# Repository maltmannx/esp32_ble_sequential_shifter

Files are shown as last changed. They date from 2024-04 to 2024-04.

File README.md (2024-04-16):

# DIY Sequential Shifter ESP32 BLE ver.
## *This project is still in progress and will subject to change.*
**This project was beased on** https://www.thingiverse.com/thing:4557771  
I simplify the code and manage to make it possible running on a Espressif ESP32 dev kit(no USBHID support) with BLE. 
## Dependency and Library
https://github.com/lemmingDev/ESP32-BLE-Gamepad  
This library turns ESP32 a BLE gamepad that fits multiple scenarios.
## Functions
The original code will turn ESP32 a bluetooth gamepad. When device paired, the board listens to 2 pins input (D25 and D34) as shifting up and down. The on-board led blink twice for shifting up, and once for down. When long-pressing the button (default 800ms), 2 extra physical buttons will be triggered. You can modify the io ports and functions to your like.

## Usage
+ Git clone or download the zip file and decompress.
+ Install VS Code and PlatformIO extension.
+ Select and download the right board driver (ESP32 Dev Kit).
+ Modify sequential_shifter.cpp that fits your perfers.
+ Connect the board and choose the right com port.
+ Build and upload the ROM (hold boot button).
+ Test functions and assembling.
+ Bind keys in game.

## Components needed (Chinese ver.)
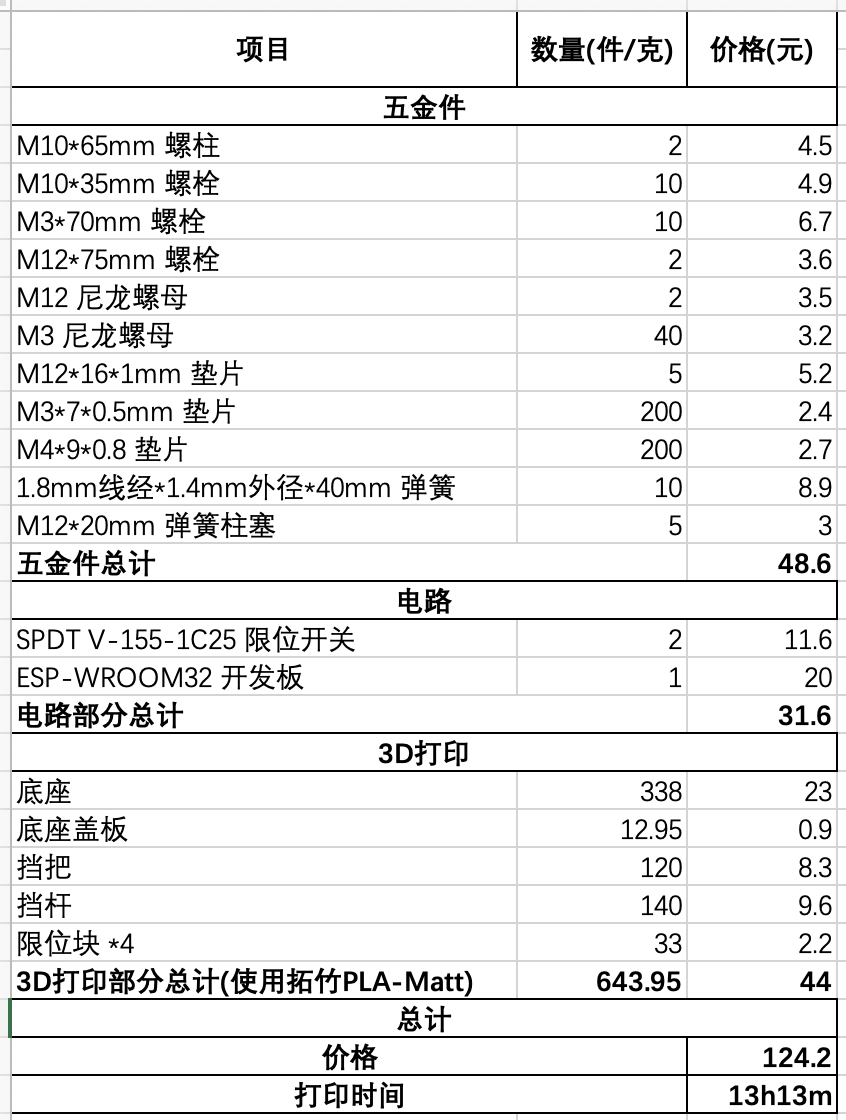
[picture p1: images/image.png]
components table

Sheets are attached above.

## About 3D printing parts
I slightly adjust the printing parameters. They're about 20% heavier but more stong and reliable. If you hava a BambuLab printer, you can simply import the .3mf file and start printing with PLA-Matt. For any non-bambulab devices, here are the per-component settings:
+ MainBody: 4 walls, 50% adaptive cubic infill with support
+ ShifterShaft: 4 walls, 50% adaptive cubic infill with support
+ Knob: 4 walls, 100% infill
+ Spacer, and bottom cover: 3 walls, 100% infill

**Total filaments used: 650.65g**  
**Total Printing time: 13h13m**

## Acknowledgements
 Introducing my friend and personal sim-racing coach @SanchezYao. I will never made it without his support.  
 Special thanks to [BambuLab](https://bambulab.com/en) for a new P1SC printer and filaments. Their products are one of the most reliable devices you can find in current days.

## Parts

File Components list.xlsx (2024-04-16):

项目 | 数量(件/克) | 价格(元)
五金件
M10*65mm 螺柱 | 2 | 4.5
M10*35mm 螺栓 | 10 | 4.9
M3*70mm 螺栓 | 10 | 6.7
M12*75mm 螺栓 | 2 | 3.6
M12 尼龙螺母 | 2 | 3.5
M3 尼龙螺母 | 40 | 3.2
M12*16*1mm 垫片 | 5 | 5.2
M3*7*0.5mm 垫片 | 200 | 2.4
M4*9*0.8 垫片 | 200 | 2.7
1.8mm线经*1.4mm外径*40mm 弹簧 | 10 | 8.9
M12*20mm 弹簧柱塞 | 5 | 3
五金件总计 |  | 48.6
电路
SPDT V-155-1C25 限位开关 | 2 | 11.6
ESP-WROOM32 开发板 | 1 | 20
电路部分总计 |  | 31.6
3D打印
底座 | 338 | 23
底座盖板 | 12.95 | 0.9
挡把 | 120 | 8.3
挡杆 | 140 | 9.6
限位块 *4 | 33 | 2.2
3D打印部分总计(使用拓竹PLA-Matt) | 643.95 | 44
总计
价格 |  | 124.2
打印时间 |  | 13h13m

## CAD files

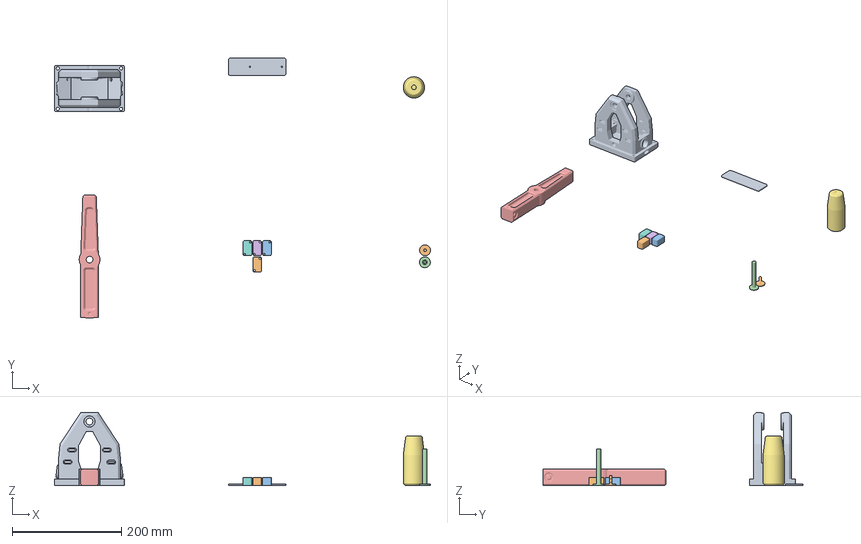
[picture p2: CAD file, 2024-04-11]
shifter.3mf
688.5 x 475.5 x 133.7 mm
MainBody.stl
PivotCap.stl
SwitchSpacer.stl x 4
PivotPin.stl
ShifterShaft.stl
Knob.stl
BottomCover.stl

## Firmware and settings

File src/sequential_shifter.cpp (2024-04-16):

#include <Arduino.h>
#include <BleGamepad.h> // https://github.com/lemmingDev/ESP32-BLE-Gamepad

#define BUTTONPIN1 5
#define BUTTONPIN2 21
// Pin button is attached to

#define LONGPRESS 500
// any pressing longer than 500ms will be triggered as long press

#define LED 2
// on-board LED(optional)

// add on-press buttons here
int button[] = {BUTTON_1, BUTTON_2};
// add on-longpress buttons here
int longPressButton[] = {BUTTON_3, BUTTON_4};

// bluetooth ssid can be modified, defalut:
// BleGamepad(std::string deviceName = "ESP32 BLE Gamepad", std::string deviceManufacturer = "Espressif", uint8_t batteryLevel = 100);
BleGamepad bleGamepad;

int previousButton1State = HIGH;
int previousButton2State = HIGH;
bool previousConnectionState = false;

unsigned long buttonPressStartTime = 0;
bool longPressTriggered = false;

// use on-board LED as connection indicator
void blink(int time, int on_time, int off_time)
{
    for (size_t i = 0; i < time; i++)
    {
        digitalWrite(LED, HIGH);
        delay(on_time);
        digitalWrite(LED, LOW);
        delay(off_time);
    }
}

void setup()
{
    pinMode(BUTTONPIN1, INPUT_PULLUP);
    pinMode(BUTTONPIN2, INPUT_PULLUP);
    bleGamepad.begin();
}

void loop()
{
    // connection indicate
    if (previousConnectionState != bleGamepad.isConnected())
    {
        blink(5, 50, 50);
    }
    else
    {
        blink(1, 500, 0);
    }

    if (bleGamepad.isConnected())
    {

        int currentButtonState[] = {digitalRead(BUTTONPIN1), digitalRead(BUTTONPIN2)};
        int previousButtonState[] = {previousButton1State, previousButton2State};

        int size = sizeof(currentButtonState) / sizeof(currentButtonState[0]);
        for (int i = 0; i < size; i++)
        {
            if (currentButtonState[i] != previousButtonState[i])
            {
                if (currentButtonState[i] == LOW)
                {
                    buttonPressStartTime = millis();
                }
                else
                {
                    unsigned long buttonPressDuration = millis() - buttonPressStartTime;
                    if (buttonPressDuration < LONGPRESS && !longPressTriggered)
                    {
                        bleGamepad.press(button[i]);
                    }
                    else if (buttonPressDuration > LONGPRESS)
                    {
                        bleGamepad.press(longPressButton[i]);
                        longPressTriggered = true;
                    }
                    buttonPressStartTime = 0;
                }
            }
        }

        previousButtonState[0] = currentButtonState[0];
        previousButtonState[1] = currentButtonState[1];
        bleGamepad.sendReport();
        delay(20);
    }
}

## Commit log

2024-04-11 add readme
    [shifter.3mf]
2024-04-11 add long press action
    [Components list.xlsx]
2024-04-16 update components list
    [Components list.xlsx]
